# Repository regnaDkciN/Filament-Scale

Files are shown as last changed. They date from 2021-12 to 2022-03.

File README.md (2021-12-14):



# General

Like many other 3D printer users, I often find myself in a situation where I’m not sure if the spool I want to use has enough filament left to complete a print.  It is a guessing game in which I too often lose.  As a result, I created a scale that gives an accurate estimate of the amount of filament left on a given spool.  A quick internet search found several projects which were designed to do just that.  However, none of them were exactly what I was looking for.  Most of the projects were very well done.  Here are some of the scales that I especially liked:

- 	**Filament Health Monitor** at https://replicantfx.com/filament-health-monitor/ .  This scale gives humidity, temperature, and automatic detection of the color of the filament that is loaded..
- 	**Build a 3D Printer Filament Scale** in Nuts and Volts Magazine 2019/Issue-4.  For Nuts and Volts subscribers it can be found at https://nutsvolts.texterity.com/nutsvolts/201904/MobilePagedReplica.action?pm=2&folio=44#pg44 This scale is very well done and very well documented.  Some notable features are a database for many common filament types, latest settings are preserved through power cycles, and a nice display that uses a rotary encoder for selection.
- 	**Filament Holder and Scales** at https://www.youmagine.com/designs/filament-holder-and-scales .  This scale has fairly simple functionality, but I liked the 3D printed spool holder it presented, and I used it in my project.
- 	**3D Printer Filament Measuring with Arduino** at https://www.electroschematics.com/3d-printer-filament-measuring-arduino/ .  This scale is nice, but simple.

# Features

The scale presented here has the following features that I deemed useful:

- 	Accurate measurement of weight up to 5 kg with units selection of grams (g), kilograms (kg), ounces (oz), or pounds (lb).
- 	Accurate measure of filament length based on spool weight and filament density.  Length units are selectable as millimeters (mm), centimeters (cm), meters (m), inches (in), feet (ft), or yards (yd).
- 	Extensive user interface using a color 1.8” TFT display and rotary encoder.
- 	Menu driven option settings.
- 	Displays environmental data of temperature and humidity with selectable Fahrenheit/Celsius selection.
- 	Database of up to 15 spools with associated ID string, empty spool weight, filament color, filament type, filament density, and filament diameter.
- 	Database of default filament densities with 12 built-in default densities, and 3 user definable densities.
- 	WiFi compatible, with built-in web page.
- 	Non-volatile storage of all user settings which are preserved through power cycles.

#

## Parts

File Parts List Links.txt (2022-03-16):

Part                                      #   Link
------------------------------------------------------------------------------------------------------------------------------------------------------------------------------------------------------------------
Adafruit HUZZAH32 – ESP32 Feather         1   https://learn.adafruit.com/adafruit-huzzah32-esp32-feather
Adafruit 1.8” TFT Display                 1   https://www.adafruit.com/product/358
HX711 ADC Converter with 5KG Load Cell    1   https://www.amazon.com/gp/product/B078W2VCP2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
DHT22 Temperature and Humidity Sensor     1   https://www.adafruit.com/product/385
Rotary Encoder with Switch Module         1   https://www.microcenter.com/product/618904/inland-ks0013-keystudio-rotary-encoder-module
SPST N.O. Pushbutton Switch (16mm)        1   https://www.amazon.com/gp/product/B07DM2YMT4/ref=ppx_yo_dt_b_asin_title_o01_s00?ie=UTF8&psc=1
DPDT Rocker Switch (3/4”)                 1   https://www.radioshack.com/products/dpdt-red-rocker-switch
Resistor, 10K 1/8 Watt                    1
5V Power Supply with Micro USB Connector  1   https://www.microcenter.com/product/510437/micro-connectors-micro-usb-5v-25a-power-adapter-with-on-off-switch-for-raspberry-pi
2-Pin Connector, 0.1”                     1   https://www.allelectronics.com/item/con-242/2-pin-connector-w/header-.10/1.html
3-Pin Connector, 0.1”                     1   https://www.allelectronics.com/item/con-243/3-pin-connector-w/header-0.1/1.html
4-Pin Connector, 0.1”                     3   https://www.allelectronics.com/item/con-244/4-pin-connector-w/header-0.10/1.html
10-Pin Connector, 0.1”                    1   https://www.allelectronics.com/item/con-2410/10-pin-connector-w/header-0.1-spacing/1.html
Hookup Wire
608ZZ Bearing                             4   https://www.amazon.com/gp/product/B00NX1WBA0/ref=ppx_yo_dt_b_asin_title_o03_s00?ie=UTF8&psc=1
Assorted M2 and M3 Screws
M3 Threaded Brass Inserts                15   https://www.amazon.com/gp/product/B07NBTCHP1/ref=ppx_yo_dt_b_asin_title_o04_s00?ie=UTF8&psc=1
M3 x 6mm Screw                           15
M3 x 12mm Screw                           6
½” Self-Adhesive Foam Pads                4   https://www.acehardware.com/departments/home-and-decor/cabinet-and-furniture-hardware/protective-furniture-pads/5089586
½” Rubber Grommet                         1   https://www.harborfreight.com/180-piece-harness-grommet-set-67582.html
4” Cable Ties (100 pack)                  5   https://www.harborfreight.com/4-in-white-cable-ties-100-pk-60257.html
3/32” Heat Shrink Tubing                      https://www.harborfreight.com/127-piece-heat-shrink-tubing-set-67524.html
Knob for Rotary Encoder

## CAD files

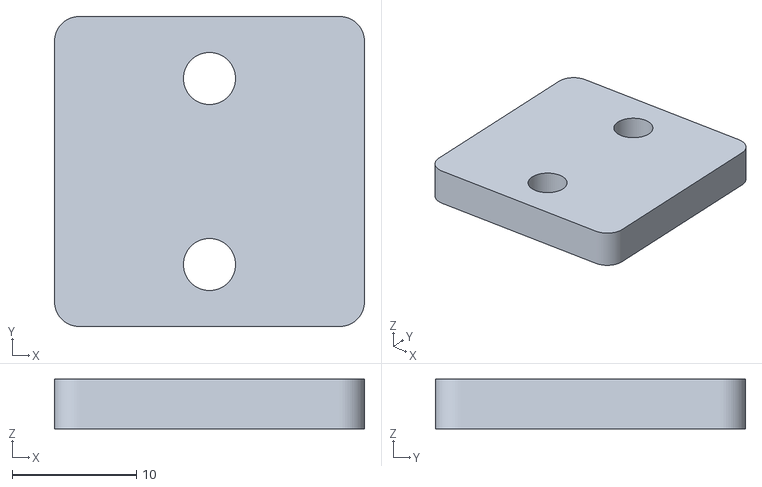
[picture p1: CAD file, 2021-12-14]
STL Files/Filament Scale - Load Cell Mount.stl
25.0 x 25.0 x 4.00

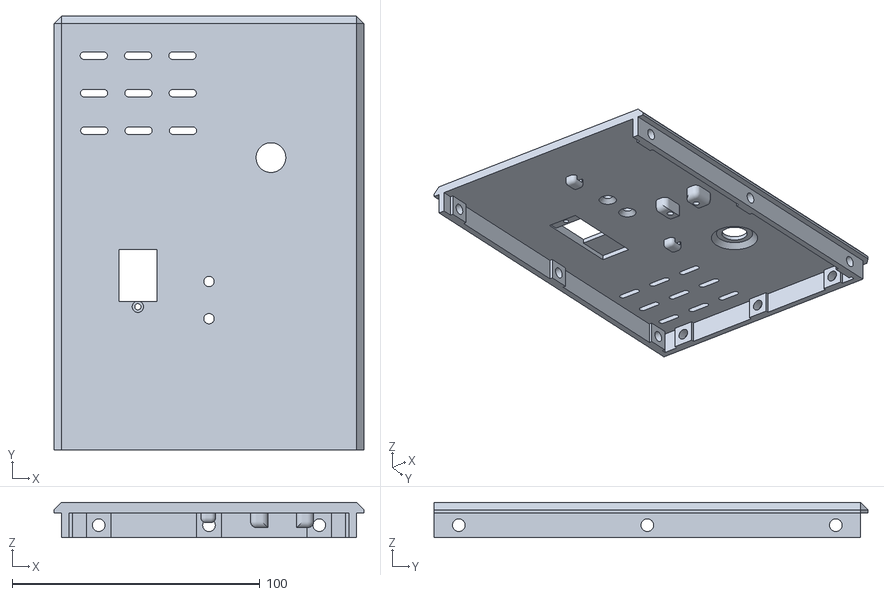
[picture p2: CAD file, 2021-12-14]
STL Files/Filament Scale - Top.stl
125.0 x 175.1 x 14.2

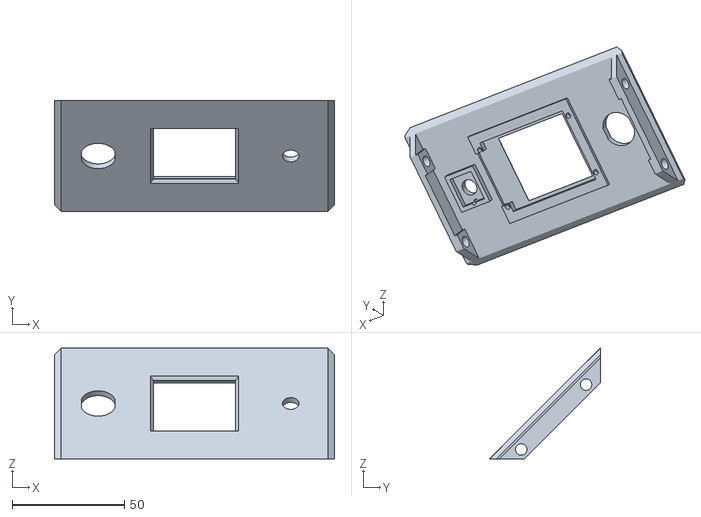
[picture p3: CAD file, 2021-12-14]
STL Files/Filament Scale - Sloped Front.stl
125.0 x 49.5 x 49.5

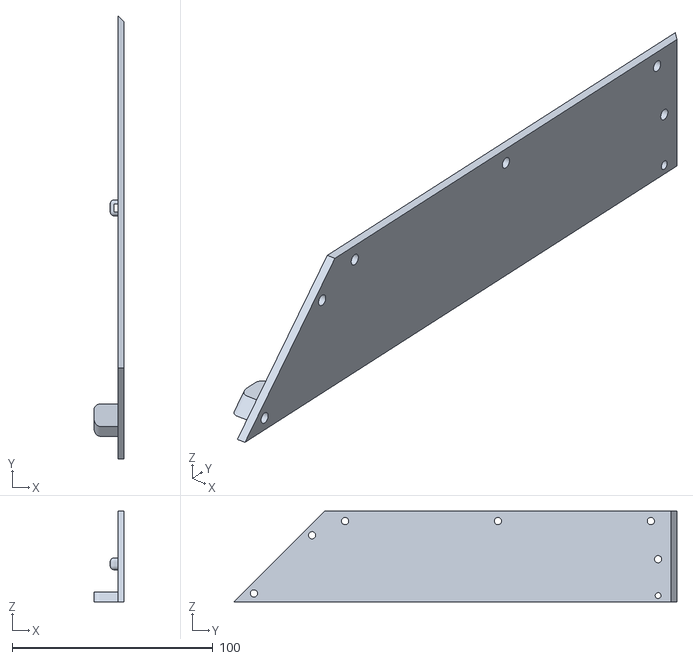
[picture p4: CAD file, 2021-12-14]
STL Files/Filament Scale - Right Side.stl
15.0 x 220.4 x 45.3

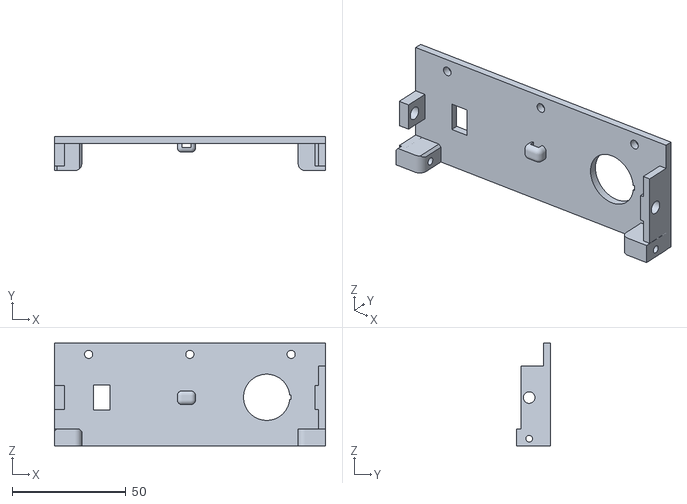
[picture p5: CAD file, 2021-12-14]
STL Files/Filament Scale - Back.stl
119.1 x 15.0 x 45.3

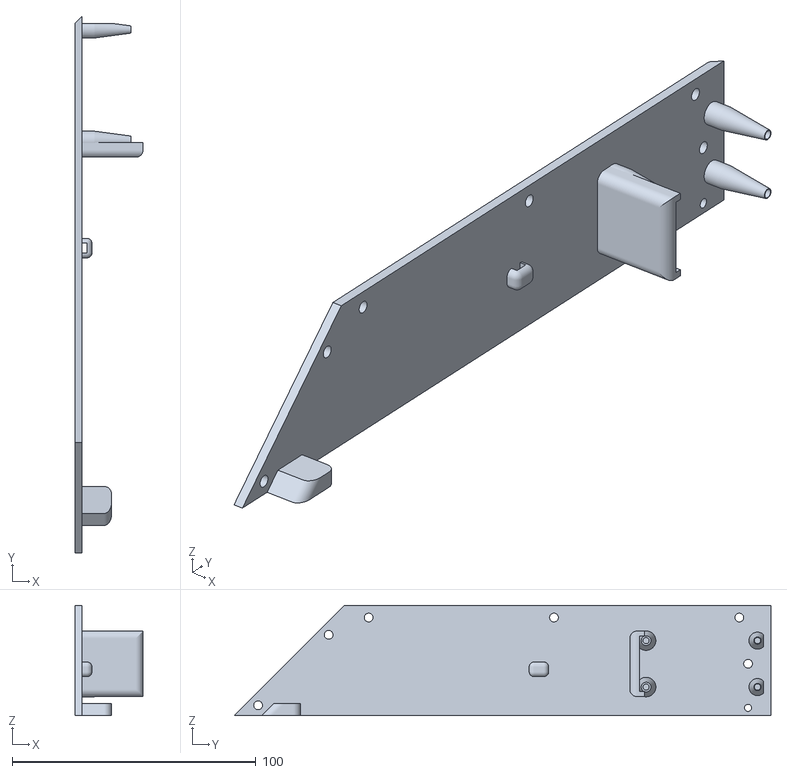
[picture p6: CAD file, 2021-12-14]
STL Files/Filament Scale - Left Side.stl
28.0 x 220.4 x 45.3

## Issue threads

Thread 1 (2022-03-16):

BOM links do not work

mmally, 2022-03-16:
First congratulations to this fine scale! I would like to build one of my own, but and try to source the components.
Which is not that easy in Europe.

In the "Filament Scale Instructions.pdf" the Hardware Parts links do not work. Other links in the pdf work fine.
I tested it with two different viewers.
This would save me a lot of work.

regnaDkciN, 2022-03-16:
I'm glad you liked it.  Thanks for catching the absence of the links.  I don't know why they don't work.  I've attached a text version of the parts list with links to this email.  I'll post a copy of it to the github site.
Good luck with your build.

    On Wednesday, March 16, 2022, 10:00:20 AM EDT, mmally ***@***.***> wrote:

First congratulations to this fine scale! I would like to build one of my own, but and try to source the components.
Which is not that easy in Europe.

In the "Filament Scale Instructions.pdf" the Hardware Parts links do not work. Other links in the pdf work fine.
I tested it with two different viewers.
This would save me a lot of work.

—
Reply to this email directly, view it on GitHub, or unsubscribe.
Triage notifications on the go with GitHub Mobile for iOS or Android.
You are receiving this because you are subscribed to this thread.Message ID: ***@***.***>

Part                                      #   Link
------------------------------------------------------------------------------------------------------------------------------------------------------------------------------------------------------------------
Adafruit HUZZAH32 – ESP32 Feather         1   https://learn.adafruit.com/adafruit-huzzah32-esp32-feather
Adafruit 1.8” TFT Display                 1   https://www.adafruit.com/product/358
HX711 ADC Converter with 5KG Load Cell    1   https://www.amazon.com/gp/product/B078W2VCP2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
DHT22 Temperature and Humidity Sensor     1   https://www.adafruit.com/product/385
Rotary Encoder with Switch Module         1   https://www.microcenter.com/product/618904/inland-ks0013-keystudio-rotary-encoder-module
SPST N.O. Pushbutton Switch (16mm)        1   https://www.amazon.com/gp/product/B07DM2YMT4/ref=ppx_yo_dt_b_asin_title_o01_s00?ie=UTF8&psc=1
DPDT Rocker Switch (3/4”)                 1   https://www.radioshack.com/products/dpdt-red-rocker-switch
Resistor, 10K 1/8 Watt                    1
5V Power Supply with Micro USB Connector  1   https://www.microcenter.com/product/510437/micro-connectors-micro-usb-5v-25a-power-adapter-with-on-off-switch-for-raspberry-pi
2-Pin Connector, 0.1”                     1   https://www.allelectronics.com/item/con-242/2-pin-connector-w/header-.10/1.html
3-Pin Connector, 0.1”                     1   https://www.allelectronics.com/item/con-243/3-pin-connector-w/header-0.1/1.html
4-Pin Connector, 0.1”                     3   https://www.allelectronics.com/item/con-244/4-pin-connector-w/header-0.10/1.html
10-Pin Connector, 0.1”                    1   https://www.allelectronics.com/item/con-2410/10-pin-connector-w/header-0.1-spacing/1.html
Hookup Wire
608ZZ Bearing                             4   https://www.amazon.com/gp/product/B00NX1WBA0/ref=ppx_yo_dt_b_asin_title_o03_s00?ie=UTF8&psc=1
Assorted M2 and M3 Screws
M3 Threaded Brass Inserts                15   https://www.amazon.com/gp/product/B07NBTCHP1/ref=ppx_yo_dt_b_asin_title_o04_s00?ie=UTF8&psc=1
M3 x 6mm Screw                           15
M3 x 12mm Screw                           6
½” Self-Adhesive Foam Pads                4   https://www.acehardware.com/departments/home-and-decor/cabinet-and-furniture-hardware/protective-furniture-pads/5089586
½” Rubber Grommet                         1   https://www.harborfreight.com/180-piece-harness-grommet-set-67582.html
4” Cable Ties (100 pack)                  5   https://www.harborfreight.com/4-in-white-cable-ties-100-pk-60257.html
3/32” Heat Shrink Tubing                      https://www.harborfreight.com/127-piece-heat-shrink-tubing-set-67524.html
Knob for Rotary Encoder

mmally, 2022-03-17:
Thank you very much for the BOM.

What is the reason for limiting the spool database to 15?

I have seen that the TFT Display also has a SD Card slot. I am thinking about using this for storing all the filament spool data (currently I have about 50 of them). Adafruit uses this just for  storing pictures, so I am not sure if it is also accessible via SPI and regular libraries.
I also have an idea to add an RFID reader to automatically identify a spool and update the database automatically.

regnaDkciN, 2022-03-17:
The main reason that the database is limited to 15 entries is that the menu system can only handle a maximum of 15 items per page.  I suppose you might be able to add multiple pages for the database, or modify the menu code to support more than 15 items.  However, I was a professional programmer for 40 years and I found the ArduinoMenu library extremely difficult to work with.  It uses deeply nested macros and contains only a few comments.  I spent more time trying to get it to do what I needed than I did on the entire rest of the project.
The storage for the database is not a problem.  I think there is enough memory left over in the system to support 50 spools.  However, it would be easy to use the SD card slot for that purpose if you wanted to.  My initial tests with the SD card slot on the TFT display showed that it was pretty easy to use.  You may have noticed on the wiring diagram that the SD card select is wired to the Huzzah even though the software does not use it.  So all you would need to do would be to add the appropriate library and interface to it.
The RFID sounds like a great idea.  I don't think it would be very difficult to add.  Of course there would be some code changes in both the menu subsystem and the main system that would be needed.

    On Thursday, March 17, 2022, 06:17:55 AM EDT, mmally ***@***.***> wrote:

Thank you very much for the BOM.

What is the reason for limiting the spool database to 15?

I have seen that the TFT Display also has a SD Card slot. I am thinking about using this for storing all the filament spool data (currently I have about 50 of them). Adafruit uses this just for storing pictures, so I am not sure if it is also accessible via SPI and regular libraries.
I also have an idea to add an RFID reader to automatically identify a spool and update the database automatically.

—
Reply to this email directly, view it on GitHub, or unsubscribe.
Triage notifications on the go with GitHub Mobile for iOS or Android.
You are receiving this because you modified the open/close state.Message ID: ***@***.***>

mmally, 2022-03-17:
Thank you for the valuable input regarding the menu library.
I will first build the scale, add RFID and then think about how to expand the database.

Cheers from Austria

regnaDkciN, 2022-03-17:
I'm glad I could help.  I hope your build goes well.

    On Thursday, March 17, 2022, 05:44:37 PM EDT, mmally ***@***.***> wrote:

Thank you for the valuable input regarding the menu library.
I will first build the scale, add RFID and then think about how to expand the database.

Cheers from Austria

—
Reply to this email directly, view it on GitHub, or unsubscribe.
Triage notifications on the go with GitHub Mobile for iOS or Android.
You are receiving this because you modified the open/close state.Message ID: ***@***.***>

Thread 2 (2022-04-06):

Wont compile - "passing 'const LoadCell' as 'this' argument discards qualifiers [-fpermissive]"

bencoton, 2022-04-06:
Can you please help with the code? I am having multiple failures however the failure in the title seems to be the greatest failure.

I am using Arduino IDE 1.8.19

In file included from C:\Users\bcoto\OneDrive\Desktop\Filament Scale\Filament-Scale-main\SourceFiles\JmcFilamentScale\LoadCell.cpp:13:0:
C:\Users\bcoto\OneDrive\Desktop\Filament Scale\Filament-Scale-main\SourceFiles\JmcFilamentScale\LoadCell.h: In member function 'int32_t LoadCell::ReadARawValue() const':
LoadCell.h:336:50: error: passing 'const LoadCell' as 'this' argument discards qualifiers [-fpermissive]
     int32_t ReadARawValue()  const { return read(); }
                                                  ^
In file included from C:\Users\bcoto\OneDrive\Desktop\Filament Scale\Filament-Scale-main\SourceFiles\JmcFilamentScale\LoadCell.h:17:0,
                 from C:\Users\bcoto\OneDrive\Desktop\Filament Scale\Filament-Scale-main\SourceFiles\JmcFilamentScale\LoadCell.cpp:13:
C:\Users\bcoto\OneDrive\Documents\Arduino\libraries\HX711/HX711.h:54:12: note:   in call to 'float HX711::read()'
   float    read();
            ^
In file included from C:\Users\bcoto\OneDrive\Desktop\Filament Scale\Filament-Scale-main\SourceFiles\JmcFilamentScale\LoadCell.cpp:13:0:
C:\Users\bcoto\OneDrive\Desktop\Filament Scale\Filament-Scale-main\SourceFiles\JmcFilamentScale\LoadCell.h: In member function 'double LoadCell::ReadARawValueD() const':
LoadCell.h:337:70: error: passing 'const LoadCell' as 'this' argument discards qualifiers [-fpermissive]
     double  ReadARawValueD() const { return static_cast<double>(read()); }
                                                                      ^
In file included from C:\Users\bcoto\OneDrive\Desktop\Filament Scale\Filament-Scale-main\SourceFiles\JmcFilamentScale\LoadCell.h:17:0,
                 from C:\Users\bcoto\OneDrive\Desktop\Filament Scale\Filament-Scale-main\SourceFiles\JmcFilamentScale\LoadCell.cpp:13:
C:\Users\bcoto\OneDrive\Documents\Arduino\libraries\HX711/HX711.h:54:12: note:   in call to 'float HX711::read()'
   float    read();
            ^
C:\Users\bcoto\OneDrive\Desktop\Filament Scale\Filament-Scale-main\SourceFiles\JmcFilamentScale\LoadCell.cpp: In constructor 'LoadCell::LoadCell(int, int, uint8_t)':
LoadCell.cpp:49:26: error: no matching function for call to 'LoadCell::begin(int&, int&, uint8_t&)'
     begin(dout, sck, gain);
                          ^
In file included from C:\Users\bcoto\OneDrive\Desktop\Filament Scale\Filament-Scale-main\SourceFiles\JmcFilamentScale\LoadCell.h:17:0,
                 from C:\Users\bcoto\OneDrive\Desktop\Filament Scale\Filament-Scale-main\SourceFiles\JmcFilamentScale\LoadCell.cpp:13:
C:\Users\bcoto\OneDrive\Documents\Arduino\libraries\HX711/HX711.h:38:12: note: candidate: void HX711::begin(uint8_t, uint8_t)
   void     begin(uint8_t dataPin, uint8_t clockPin);
            ^
C:\Users\bcoto\OneDrive\Documents\Arduino\libraries\HX711/HX711.h:38:12: note:   candidate expects 2 arguments, 3 provided
C:\Users\bcoto\OneDrive\Desktop\Filament Scale\Filament-Scale-main\SourceFiles\JmcFilamentScale\LoadCell.cpp: In member function 'bool LoadCell::IsPresent() const':
LoadCell.cpp:142:35: error: passing 'const LoadCell' as 'this' argument discards qualifiers [-fpermissive]
     if (!wait_ready_retry(10U, 10U) || (ReadARawValue() == 0L))
                                   ^
In file included from C:\Users\bcoto\OneDrive\Desktop\Filament Scale\Filament-Scale-main\SourceFiles\JmcFilamentScale\LoadCell.h:17:0,
                 from C:\Users\bcoto\OneDrive\Desktop\Filament Scale\Filament-Scale-main\SourceFiles\JmcFilamentScale\LoadCell.cpp:13:
C:\Users\bcoto\OneDrive\Documents\Arduino\libraries\HX711/HX711.h:49:12: note:   in call to 'bool HX711::wait_ready_retry(uint8_t, uint32_t)'
   bool     wait_ready_retry(uint8_t retries = 3, uint32_t ms = 0);
            ^
At global scope:
cc1plus.exe: warning: unrecognized command line option '-Wno-frame-address'
In file included from C:\Users\bcoto\OneDrive\Desktop\Filament Scale\Filament-Scale-main\SourceFiles\JmcFilamentScale\JmcFilamentScale.h:16:0,
                 from C:\Users\bcoto\OneDrive\Desktop\Filament Scale\Filament-Scale-main\SourceFiles\JmcFilamentScale\HslColor.h:16,
                 from C:\Users\bcoto\OneDrive\Desktop\Filament Scale\Filament-Scale-main\SourceFiles\JmcFilamentScale\HslColor.cpp:14:
C:\Users\bcoto\OneDrive\Desktop\Filament Scale\Filament-Scale-main\SourceFiles\JmcFilamentScale\LoadCell.h: In member function 'int32_t LoadCell::ReadARawValue() const':
LoadCell.h:336:50: error: passing 'const LoadCell' as 'this' argument discards qualifiers [-fpermissive]
     int32_t ReadARawValue()  const { return read(); }
                                                  ^
In file included from C:\Users\bcoto\OneDrive\Desktop\Filament Scale\Filament-Scale-main\SourceFiles\JmcFilamentScale\LoadCell.h:17:0,
                 from C:\Users\bcoto\OneDrive\Desktop\Filament Scale\Filament-Scale-main\SourceFiles\JmcFilamentScale\JmcFilamentScale.h:16,
                 from C:\Users\bcoto\OneDrive\Desktop\Filament Scale\Filament-Scale-main\SourceFiles\JmcFilamentScale\HslColor.h:16,
                 from C:\Users\bcoto\OneDrive\Desktop\Filament Scale\Filament-Scale-main\SourceFiles\JmcFilamentScale\HslColor.cpp:14:
C:\Users\bcoto\OneDrive\Documents\Arduino\libraries\HX711/HX711.h:54:12: note:   in call to 'float HX711::read()'
   float    read();
            ^
In file included from C:\Users\bcoto\OneDrive\Desktop\Filament Scale\Filament-Scale-main\SourceFiles\JmcFilamentScale\JmcFilamentScale.h:16:0,
                 from C:\Users\bcoto\OneDrive\Desktop\Filament Scale\Filament-Scale-main\SourceFiles\JmcFilamentScale\HslColor.h:16,
                 from C:\Users\bcoto\OneDrive\Desktop\Filament Scale\Filament-Scale-main\SourceFiles\JmcFilamentScale\HslColor.cpp:14:
C:\Users\bcoto\OneDrive\Desktop\Filament Scale\Filament-Scale-main\SourceFiles\JmcFilamentScale\LoadCell.h: In member function 'double LoadCell::ReadARawValueD() const':
LoadCell.h:337:70: error: passing 'const LoadCell' as 'this' argument discards qualifiers [-fpermissive]
     double  ReadARawValueD() const { return static_cast<double>(read()); }
                                                                      ^
In file included from C:\Users\bcoto\OneDrive\Desktop\Filament Scale\Filament-Scale-main\SourceFiles\JmcFilamentScale\LoadCell.h:17:0,
                 from C:\Users\bcoto\OneDrive\Desktop\Filament Scale\Filament-Scale-main\SourceFiles\JmcFilamentScale\JmcFilamentScale.h:16,
                 from C:\Users\bcoto\OneDrive\Desktop\Filament Scale\Filament-Scale-main\SourceFiles\JmcFilamentScale\HslColor.h:16,
                 from C:\Users\bcoto\OneDrive\Desktop\Filament Scale\Filament-Scale-main\SourceFiles\JmcFilamentScale\HslColor.cpp:14:
C:\Users\bcoto\OneDrive\Documents\Arduino\libraries\HX711/HX711.h:54:12: note:   in call to 'float HX711::read()'
   float    read();
            ^
In file included from C:\Users\bcoto\OneDrive\Desktop\Filament Scale\Filament-Scale-main\SourceFiles\JmcFilamentScale\JmcFilamentScale.h:18:0,
                 from C:\Users\bcoto\OneDrive\Desktop\Filament Scale\Filament-Scale-main\SourceFiles\JmcFilamentScale\HslColor.h:16,
                 from C:\Users\bcoto\OneDrive\Desktop\Filament Scale\Filament-Scale-main\SourceFiles\JmcFilamentScale\HslColor.cpp:14:
C:\Users\bcoto\OneDrive\Desktop\Filament Scale\Filament-Scale-main\SourceFiles\JmcFilamentScale\SpoolManager.h: In member function 'bool SpoolManager<N>::Save() const':
SpoolManager.h:406:9: error: 'Preferences' was not declared in this scope
         Preferences prefs;
         ^
SpoolManager.h:407:9: error: 'prefs' was not declared in this scope
         prefs.begin(m_pName);
         ^
C:\Users\bcoto\OneDrive\Desktop\Filament Scale\Filament-Scale-main\SourceFiles\JmcFilamentScale\SpoolManager.h: In member function 'bool SpoolManager<N>::Restore()':
SpoolManager.h:460:9: error: 'Preferences' was not declared in this scope
         Preferences prefs;
         ^
SpoolManager.h:461:9: error: 'prefs' was not declared in this scope
         prefs.begin(m_pName);
         ^
C:\Users\bcoto\OneDrive\Desktop\Filament Scale\Filament-Scale-main\SourceFiles\JmcFilamentScale\SpoolManager.h: In member function 'bool SpoolManager<N>::Reset()':
SpoolManager.h:498:9: error: 'Preferences' was not declared in this scope
         Preferences prefs;
         ^
SpoolManager.h:499:9: error: 'prefs' was not declared in this scope
         prefs.begin(m_pName);
         ^
In file included from C:\Users\bcoto\OneDrive\Desktop\Filament Scale\Filament-Scale-main\SourceFiles\JmcFilamentScale\JmcFilamentScale.h:16:0,
                 from C:\Users\bcoto\OneDrive\Desktop\Filament Scale\Filament-Scale-main\SourceFiles\JmcFilamentScale\MainScreen.cpp:12:
C:\Users\bcoto\OneDrive\Desktop\Filament Scale\Filament-Scale-main\SourceFiles\JmcFilamentScale\LoadCell.h: In member function 'int32_t LoadCell::ReadARawValue() const':
LoadCell.h:336:50: error: passing 'const LoadCell' as 'this' argument discards qualifiers [-fpermissive]
     int32_t ReadARawValue()  const { return read(); }
                                                  ^
In file included from C:\Users\bcoto\OneDrive\Desktop\Filament Scale\Filament-Scale-main\SourceFiles\JmcFilamentScale\LoadCell.h:17:0,
                 from C:\Users\bcoto\OneDrive\Desktop\Filament Scale\Filament-Scale-main\SourceFiles\JmcFilamentScale\JmcFilamentScale.h:16,
                 from C:\Users\bcoto\OneDrive\Desktop\Filament Scale\Filament-Scale-main\SourceFiles\JmcFilamentScale\MainScreen.cpp:12:
C:\Users\bcoto\OneDrive\Documents\Arduino\libraries\HX711/HX711.h:54:12: note:   in call to 'float HX711::read()'
   float    read();
            ^
In file included from C:\Users\bcoto\OneDrive\Desktop\Filament Scale\Filament-Scale-main\SourceFiles\JmcFilamentScale\JmcFilamentScale.h:16:0,
                 from C:\Users\bcoto\OneDrive\Desktop\Filament Scale\Filament-Scale-main\SourceFiles\JmcFilamentScale\MainScreen.cpp:12:
C:\Users\bcoto\OneDrive\Desktop\Filament Scale\Filament-Scale-main\SourceFiles\JmcFilamentScale\LoadCell.h: In member function 'double LoadCell::ReadARawValueD() const':
LoadCell.h:337:70: error: passing 'const LoadCell' as 'this' argument discards qualifiers [-fpermissive]
     double  ReadARawValueD() const { return static_cast<double>(read()); }
                                                                      ^
In file included from C:\Users\bcoto\OneDrive\Desktop\Filament Scale\Filament-Scale-main\SourceFiles\JmcFilamentScale\LoadCell.h:17:0,
                 from C:\Users\bcoto\OneDrive\Desktop\Filament Scale\Filament-Scale-main\SourceFiles\JmcFilamentScale\JmcFilamentScale.h:16,
                 from C:\Users\bcoto\OneDrive\Desktop\Filament Scale\Filament-Scale-main\SourceFiles\JmcFilamentScale\MainScreen.cpp:12:
C:\Users\bcoto\OneDrive\Documents\Arduino\libraries\HX711/HX711.h:54:12: note:   in call to 'float HX711::read()'
   float    read();
            ^
In file included from C:\Users\bcoto\OneDrive\Desktop\Filament Scale\Filament-Scale-main\SourceFiles\JmcFilamentScale\JmcFilamentScale.h:18:0,
                 from C:\Users\bcoto\OneDrive\Desktop\Filament Scale\Filament-Scale-main\SourceFiles\JmcFilamentScale\MainScreen.cpp:12:
C:\Users\bcoto\OneDrive\Desktop\Filament Scale\Filament-Scale-main\SourceFiles\JmcFilamentScale\SpoolManager.h: In member function 'bool SpoolManager<N>::Save() const':
SpoolManager.h:406:9: error: 'Preferences' was not declared in this scope
         Preferences prefs;
         ^
SpoolManager.h:407:9: error: 'prefs' was not declared in this scope
         prefs.begin(m_pName);
         ^
C:\Users\bcoto\OneDrive\Desktop\Filament Scale\Filament-Scale-main\SourceFiles\JmcFilamentScale\SpoolManager.h: In member function 'bool SpoolManager<N>::Restore()':
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

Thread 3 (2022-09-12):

Some errors while trying to build

xyzroe, 2022-09-12:
Hi.
Great work, thanks.
I'm trying to build firmware using your instruction (new clean Arduino IDE v1.8.19, all libraries from table 4 were installed, menu and hx711 files were replaced) but I got a few errors that I tried to fix.
So far I have not had success, but maybe you can help me.

1. _DHT.h: No such file or directory_  - I tried different versions of 'DHT sensor library for ESPx', but all of them used DHTesp.h not DHT.h as in your project. I change to DHTesp.h, according to https://github.com/beegee-tokyo/DHTesp/blob/master/examples/DHT_ESP32/DHT_ESP32.ino#L1
2. _WiFiManager.h: No such file or directory_  - I installed https://github.com/tzapu/WiFiManager that is not mentioned in table 4, but I found this link at https://github.com/regnaDkciN/Filament-Scale/blob/03aa03c5be18ce4ef94d06465c40cf69e46beec1/SourceFiles/JmcFilamentScale/Network.h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
3. _JmcFilamentScale\EnvSensor.cpp:13: EnvSensor.h:35:1: error: expected class-name before '{' token_  - I changed 'class EnvSensor : private DHT' to 'class EnvSensor : private DHTesp'
4. _EnvSensor.h:41:15: error: class 'EnvSensor' does not have any field named 'DHT'_ - I changed 'DHT(dataPin, type)' to 'DHTesp(dataPin, type)'
5. _EnvSensor.h:41:81: error: no matching function for call to 'DHTesp::DHTesp(uint8_t&, uint8_t&)'_ - And here I have no more ideas.

Maybe I need to install some other library for DHT?

What am I doing wrong?

UPD: I installed [DHT sensor library](https://github.com/adafruit/DHT-sensor-library) and it turned out to be a successful build. I will test.

xyzroe, 2022-09-12:
I made a [fork](https://github.com/xyzroe/Filament-Scale) that supports PlatformIO right out of the box.

The main advantage is that you do not need to download the libraries by hand - everything will be downloaded by itself at the time of the first build of the project.
There is also no need to replace the library files, since the two libraries that need to be changed are included in the project with all the necessary changes.
I tried to make a minimum of changes in the project files in order to leave the opportunity to develop using Arduino IDE.

If you find an opportunity to study my solution and it seems interesting and acceptable to you, I will gladly make a PR.

regnaDkciN, 2022-09-12:
Hi xyzroe,
Does this mean you overcame the errors you reported earlier?  I've only recently started using PlatformIO and am glad that you made a fork for it.I will check your fork when I get a chance.  May take a few days.
Joe

    On Monday, September 12, 2022 at 02:08:13 PM EDT, xyzroe ***@***.***> wrote:

I made a fork that supports PlatformIO right out of the box.

The main advantage is that you do not need to download the libraries by hand - everything will be downloaded by itself at the time of the first build of the project.
There is also no need to replace the library files, since the two libraries that need to be changed are included in the project with all the necessary changes.
I tried to make a minimum of changes in the project files in order to leave the opportunity to develop using Arduino IDE.

If you find an opportunity to study my solution and it seems interesting and acceptable to you, I will gladly make a PR.

—
Reply to this email directly, view it on GitHub, or unsubscribe.
You are receiving this because you are subscribed to this thread.Message ID: ***@***.***>

xyzroe, 2022-09-12:
Yes, I overcame those errors. I edited the first message as soon as I found the solution.

Regarding the fork: I made the possibility of automatic build directly on GitHub, it seems to me convenient.
Also made a little order in the organization of the files, so that the repository would look easier.

So far, I don’t have a weight sensor or a screen, so I can’t do full-fledged tests. But in general, build goes without remarks, wifi connected, the DHT readings are received. So I think everything should be fine.

regnaDkciN, 2022-09-12:
Looks like I unintentionally referenced the wrong DHT library in the PDF file.  The correct one is the Adafruit "DHT sensor library"  which can be found and installed in the Arduino library manager.  It doesn't explicitly state that it works with the ESP32, but it works OK for me.  However, if your changes using DHTesp work, then by all means use them.  Regarding WiFiManager, the link in the PDF file is correct and you should have been able to find it.  However, again, if the file you found works for you then go ahead and use it.
Disclaimer: I actually started work on the scale in 2019, so some of the things (parts and / or libraries) I used may have been superseded by now, or better ones may be available.  Feel free to change whatever anything you need to make it work for you.

    On Monday, September 12, 2022 at 06:14:03 PM EDT, xyzroe ***@***.***> wrote:

Yes, I overcame those errors. I edited the first message as soon as I found the solution.

Regarding the fork: I made the possibility of automatic build directly on GitHub, it seems to me convenient.
Also made a little order in the organization of the files, so that the repository would look easier.

So far, I don’t have a weight sensor or a screen, so I can’t do full-fledged tests. But in general, build goes without remarks, wifi connected, the DHT readings are received. So I think everything should be fine.

—
Reply to this email directly, view it on GitHub, or unsubscribe.
You are receiving this because you commented.Message ID: ***@***.***>

Closed 2022-09-14.

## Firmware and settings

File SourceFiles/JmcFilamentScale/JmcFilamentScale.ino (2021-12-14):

/////////////////////////////////////////////////////////////////////////////////
// JmcFilamentScale.ino
//
// Implements a filament scale with the following features:
//   - Menu driven settings.
//   - Selectable weight units display (g, kg, oz, lb).
//   - Weigh items up to 5kg (11 lb).
//   - Addjustable display brightness.
//   - Built-in temperature display.
//   - Built-in humidity display.
//   - Selectable temperature units (degrees C or F).
//   - Storage for data for up to 15 filament spools.
//   - Adjustable spool parameters include:
//      - Spool name (up to 8 characters).
//      - Filament type (15 selectable filament types).
//      - Empty spool weight.
//      - Filament diameter.
//   - Adjustable filament density for eoach of the 15 filament types.
//   - Calculation and display of remaining length of filament per spool.
//   - Selectable filament length units (mm, cm, m, in, ft, yd).
//   - Ability to save settings to NVS for restoration on powerup.
//   - Web interface with ability to monitor all data and modify all options
//     remotely.
//
//  This implementation relies heavily on the ArdiunoMenu library:
//      https://github.com/neu-rah/ArduinoMenu
//
// This code is menat to run on an ESP32 microprocessor with the following or
// similar peripherals:
//      - Adafruit HUZZAH32 - ESP32 Feather Board.
//        https://www.adafruit.com/product/3405
//      - Adafruit 1.8" 128x160  TFT display.
//        https://www.adafruit.com/product/358
//      - 5kg Load Cell and HX711.
//        https://www.amazon.com/gp/product/B075317R45/ref=ppx_yo_dt_b_asin_title_o02_s00?ie=UTF8&psc=1
//      - DHT22 Digital Temperature and Himidity Sensor.
//        https://www.amazon.com/gp/product/B07T63JRT8/ref=ppx_yo_dt_b_asin_title_o00_s00?ie=UTF8&psc=1
//      - Rotaty Encoder with Pushbutton Module.
//        https://www.amazon.com/gp/product/B081YCR3JC/ref=ppx_yo_dt_b_asin_title_o04_s00?ie=UTF8&psc=1
//
// This project was inspired by an article in "Nuts and Volts" magazine
// 2019 Issue-4.  The article is entitled "Build a 3D Printer Filament Scale" by
// Edward Andrews.  I used a few small code fragments from the article, and the
// filament density table from the article.  Additional inspiration was gathered
// from "Filament Health Monitor" at https://replicantfx.com/filament-health-monitor/
//
// History:
// - jmcorbett 04-JAN-2021 Original creation.
//
// Copyright (c) 2021, Joseph M. Corbett
/////////////////////////////////////////////////////////////////////////////////

#include "JmcFilamentScale.h"   // For global variables and extern definitioins.
#include <menu.h>               // For ArduinoMenu.
#include <menuIO/adafruitGfxOut.h>// For Adafruit graphics library.
#include <menuIO/chainStream.h> // For menu input/output streams.
#include <menuIO/serialOut.h>   // For menu serial output.
#include <menuIO/serialIn.h>    // For menu serial input.
#include <plugin/userMenu.h>    // For OBJ menu macro.
#include "ESP32EncoderStream.h" // For encoder w/pushbutton.
#include "MainScreen.h"         // For MainScreen related stuff.
#include "WebData.h"            // For web page handling code.
#include "ScaleMenu.h"          // For menu  related stuff.
#include "AuxPb.h"              // For AuxPb class.


/////////////////////////////////////////////////////////////////////////////////
// ST7735 1.8TFT 128x160 Pin assignments and related variables.
/////////////////////////////////////////////////////////////////////////////////
static const int TFT_CS   = 14;     // TFT display CS pin.
static const int TFT_DC   = 32;     // TFT display DC pin.
static const int TFT_RST  = 15;     // TFT display RST pin.
static const int TFT_LITE = A0;     // TFT display backlight pin.

// Construct our TFT  object.
// Adafruit_ST7735 gTft(TFT_CS, TFT_DC, TFT_RST);
Display gTft(TFT_CS, TFT_DC, TFT_RST, TFT_LITE);

// TFT related globals and constants.
uint32_t           gBacklightPercent = 100;
static const char *gTftNvsName       = "Dispaly";


/////////////////////////////////////////////////////////////////////////////////
// Rotary encoder pins.
/////////////////////////////////////////////////////////////////////////////////
static const int ENC_PIN_A      = A3;   // Encoder A pin.
static const int ENC_PIN_B      = A4;   // Encoder B pin.
static const int ENC_BUTTON_PIN = 13;   // Encoder pushbutton pin.
static const int ENC_SENSITIVITY = 4;   // Encoder sensitivity.

// Construct the pushbutton encoder stream object.  Note that some encoders will
// require the sensitivity to be set to a different value.
ESP32EncoderStream gEncStream(ENC_PIN_A, ENC_PIN_B, ENC_BUTTON_PIN, ENC_SENSITIVITY);


/////////////////////////////////////////////////////////////////////////////////
// Auxiliary pushbutton pins.
/////////////////////////////////////////////////////////////////////////////////
static const int AUX_BUTTON_PIN = A1;   // Auxiliary pushbutton pin.

// Construct the auxiliary pushbutton object.
AuxPb gAuxPb(AUX_BUTTON_PIN);


/////////////////////////////////////////////////////////////////////////////////
// Define the LoadCell sensor related I/O pins and global data and constants.
/////////////////////////////////////////////////////////////////////////////////
static const int LOADCELL_DOUT_PIN  = A2;   // LoadCell DOUT signal pin.
static const int LOADCELL_SCK_PIN   = A5;   // LoadCell CLOCK pin.

// Construct and init the LoadCell object.
LoadCell gLoadCell(LOADCELL_DOUT_PIN, LOADCELL_SCK_PIN, 128U);

// Load cell related globals and constants.
       WeightUnits gScaleUnits        = eWuGrams;
       uint32_t    gScaleAveragingSamples =
                   (AVG_SAMPLES_DEFAULT_MS + WEIGHT_UPDATE_PERIOD_MS / 2) /
                   WEIGHT_UPDATE_PERIOD_MS;
       uint8_t     gScaleGain         = 128;
static const char *gLoadCellNvsName   = "Load Cell";
       float       gCurrentWeight     = 0.0f;
       float       gCurrentLength     = 0.0f;


/////////////////////////////////////////////////////////////////////////////////
// Define the environmental sensor (temperature and humidity) pins and global
// data and constants.
/////////////////////////////////////////////////////////////////////////////////
static const uint8_t ENV_DAT_PIN    = 27;   // Sensor data pin.
static const uint8_t ENV_TYPE       = DHT22;// Sensor type.

// Construct and init the EnvSensor object.
EnvSensor gEnvSensor(ENV_DAT_PIN, ENV_TYPE);

// Environmental sensor related globals and constants.
TempScale gTemperatureUnits     = eTempScaleF;
static const char *gEnvSensorNvsName   = "Env Sensor";
       float       gCurrentTemperature = 0.0f;
       float       gCurrentHumidity    = 0.0f;


/////////////////////////////////////////////////////////////////////////////////
// Filament class related data and constants.
/////////////////////////////////////////////////////////////////////////////////
Filament gFilament;

// Filament related global data and constants.
       float  gWorkingFilamentDensity = 0.01;
       char   gWorkingFilamentType[Filament::TYPE_STRING_MAX_SIZE] = { 0 };
static const char *gFilamentNvsName  = "Filament";


/////////////////////////////////////////////////////////////////////////////////
// Spool Manager related data and constants.
/////////////////////////////////////////////////////////////////////////////////
SpoolManager<NUMBER_SPOOLS> gSpoolMgr;

// Set up spool related global data.  Used for dynamic menu implementation.
       SpoolData gWorkingSpoolData; // Spool data currently being worked om.
static const char *gSpoolMgrNvsName  = "Spool Mgr";


/////////////////////////////////////////////////////////////////////////////////
// LengthManager related data and constants.
/////////////////////////////////////////////////////////////////////////////////
LengthManager gLengthMgr;

// Length manager related globals and constants.
static const       LengthUnits DEFAULT_LENGTH_UNITS = luMm;
                   LengthUnits  gLengthUnits        = DEFAULT_LENGTH_UNITS;
static float       gLengthFactor                    = 0.0;
static const char *gLengthMgrNvsName                = "Length Mgr";


/////////////////////////////////////////////////////////////////////////////////
// Network related data and constants.
/////////////////////////////////////////////////////////////////////////////////
static const int   SERVER_PORT = 80;
       Network     gNetwork(SERVER_PORT);

// NVS name.
static const char *gNetworkNvsName    = "Network";

// Access the scale via this name (i.e. http://JmcScale.local).
const char *gNetworkServerName = "JmcScale";
const char * &rNetworkServerName = gNetworkServerName;


/////////////////////////////////////////////////////////////////////////////////
// Main Screen related data and constants.
/////////////////////////////////////////////////////////////////////////////////
static const char *gMainScreenNvsName = "Main Screen";


/////////////////////////////////////////////////////////////////////////////////
// Weight related data.
/////////////////////////////////////////////////////////////////////////////////
static const  double MAX_CAL_WEIGHT = 5000.0;
static const  double MIN_CAL_WEIGHT = 0.0;
       double gCalibrateWeight      = MIN_CAL_WEIGHT;
       double gMinWeight            = MIN_CAL_WEIGHT;
       double gMaxWeight            = MAX_CAL_WEIGHT;
       double gBigWeightStep        = 10.0;
       double gSmallWeightStep      = .1;


/////////////////////////////////////////////////////////////////////////////////
// Miscellaneous globals.
/////////////////////////////////////////////////////////////////////////////////
       bool   gRunningMenu          = false;
       bool   gDataUpdated          = false;

/////////////////////////////////////////////////////////////////////////////////
// SetDecimalPlaces()
//
// Rounds a double value to a specified precision (number of digits to the right
// of the decimal point).
//
// Arguments:
//  value     - this is the value that will be rounded.
//  precision - this is the number of digits to the right of the decimal point
//              to keep.
//
// Returns:
//   Returns the rounded value.
/////////////////////////////////////////////////////////////////////////////////
double SetDecimalPlaces(double value, int precision)
{
    double factor = pow(10, precision);
    value *= factor;
    value = ceil(value);
    value /= factor;
    return value;
}


/////////////////////////////////////////////////////////////////////////////////
// GetMinScaleWeight()
//
// Returns the minimum allowable scale weight given the current weight units.
// Currently always returns 0.0.  May change in the future.
/////////////////////////////////////////////////////////////////////////////////
static double GetMinScaleWeight()
{
    double minWeight = 0.0;
    switch(gLoadCell.GetUnits())
    {
    case eWuGrams:     minWeight = 0.0; break;
    case eWuKiloGrams: minWeight = 0.0; break;
    case eWuOunces:    minWeight = 0.0; break;
    case eWuPounds:    minWeight = 0.0; break;
    default:           minWeight = 0.0; break;
    }
    return minWeight;
} // End GetMinScaleWeight().


/////////////////////////////////////////////////////////////////////////////////
// GetMaxScaleWeight()
//
// Returns the maximum allowable scale weight given the current weight units.
/////////////////////////////////////////////////////////////////////////////////
double GetMaxScaleWeight()
{
    double maxWeight = 10.0;
    switch(gLoadCell.GetUnits())
    {
    case eWuGrams:     maxWeight = 5000.0; break;
    case eWuKiloGrams: maxWeight = 5.0;    break;
    case eWuOunces:    maxWeight = 176.37; break;
    case eWuPounds:    maxWeight = 11.02;  break;
    default:           maxWeight = 5000.0; break;
    }
    return maxWeight;
} // End GetMaxScaleWeight().


/////////////////////////////////////////////////////////////////////////////////
// GetWeightBigStep()
//
// Returns the size of a large step for when editing weight values based on
// the currently selected weight units.
/////////////////////////////////////////////////////////////////////////////////
static double GetWeightBigStep()
{
    double step = 10.0;
    switch(gLoadCell.GetUnits())
    {
    case eWuGrams:     step = 10.0; break;
    case eWuKiloGrams: step = 0.01; break;
    case eWuOunces:    step = 1.0;  break;
    case eWuPounds:    step = 0.1;  break;
    default:           step = 10.0; break;
    }
    return step;
} // End GetWeightBigStep().


/////////////////////////////////////////////////////////////////////////////////
// GetWeightSmallStep()
//
// Returns the size of a small step for when editing weight values based on
// the currently selected weight units.
/////////////////////////////////////////////////////////////////////////////////
static double GetWeightSmallStep()
{
    double step = 0.1;
    switch(gLoadCell.GetUnits())
    {
    case eWuGrams:     step = 0.1;    break;
    case eWuKiloGrams: step = 0.0001; break;
    case eWuOunces:    step = 0.01;   break;
    case eWuPounds:    step = 0.001;  break;
    default:           step = 0.1;    break;
    }
    return step;
} // End GetWeightSmallStep().


/////////////////////////////////////////////////////////////////////////////////
// GetWeightDecimalPlaces()
//
// Returns the number of digits to display to the right of the decimal point
// based on the currently selected weight units.
/////////////////////////////////////////////////////////////////////////////////
int GetWeightDecimalPlaces()
{
        int decimalPlaces = 1;
        switch(gLoadCell.GetUnits())
        {
        case eWuGrams:     decimalPlaces = 1; break;
        case eWuKiloGrams: decimalPlaces = 4; break;
        case eWuOunces:    decimalPlaces = 2; break;
        case eWuPounds:    decimalPlaces = 3; break;
        default:           decimalPlaces = 1; break;
        }
        return decimalPlaces;
} // End GetWeightDecimalPlaces().


/////////////////////////////////////////////////////////////////////////////////
// SaveSpoolOffset()
//
// If a spool is selected, then save its offset value as the current load cell
// offset.  Otherwise, save a value of 0.0.
/////////////////////////////////////////////////////////////////////////////////
void SaveSpoolOffset()
{
    double currentSpoolOffset = 0.0;

    Spool *pSelectedSpool = gSpoolMgr.GetSelectedSpool();
    if (pSelectedSpool != NULL)
    {
        currentSpoolOffset = pSelectedSpool->GetSpoolWeight();
    }
    gLoadCell.SetOffset(currentSpoolOffset);
} // End SaveSpoolOffset().


/////////////////////////////////////////////////////////////////////////////////
// UpdateLengthFactor()
//
// If a spool is selected, then update our length factor.  Otherwise, save a
// value of 0.0.
/////////////////////////////////////////////////////////////////////////////////
void UpdateLengthFactor()
{
    // Initially reset the length factor.
    gLengthFactor = 0.0;

    // Only update the length factor if a spool is selected.
    Spool *pSelectedSpool = gSpoolMgr.GetSelectedSpool();
    if ((gLoadCell.IsCalibrated()) && (pSelectedSpool != NULL))
    {
        gLengthFactor = gLengthMgr.CalculateLengthFactor(
                        pSelectedSpool->GetDiameter(),
                        gLoadCell.GetBaseUnitsFactor(gScaleUnits),
                        pSelectedSpool->GetDensity());
    }
} // End UpdateLengthFactor().


/////////////////////////////////////////////////////////////////////////////////
// SetLoadCellUnits()
//
// Updates our load cell (weight) units, then scales all spool table weights
// based on the new units.
/////////////////////////////////////////////////////////////////////////////////
void SetLoadCellUnits(WeightUnits units)
{
    // Update our weight units and edit limits.
    gLoadCell.SetUnits(units);
    gMinWeight = GetMinScaleWeight();
    gMaxWeight = GetMaxScaleWeight();
    gBigWeightStep   = GetWeightBigStep();
    gSmallWeightStep = GetWeightSmallStep();

    // Determine our multiplier based on the new weight units.
    double multiplier = gLoadCell.GetConversionFactor();

    // Scale the spool weights for the entire spool table based on the new units.
    for (uint16_t i = 0; i < NUMBER_SPOOLS; i++)
    {
        Spool *pSpool = gSpoolMgr.GetSpool(i);
        float weight = pSpool->GetSpoolWeight() * multiplier;
        pSpool->SetSpoolWeight(weight);
    }
} // End SetLoadCellUnits().
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
void loop()
{
    // Number of milliseconds to delay at the end of each loop() execution.
    const uint32_t LOOP_DELAY = 2;

    // Always update the scale weight and environmental data.
    UpdateCurrentWeight();
    UpdateCurrentEnv();

    // Always handle the network.
    gNetwork.Process();

    // If web had the lock and timed out, then clear the lock.
    WebData::HandleWebTimeout();

    // Handle the Aux Pushbutton.  Must be done before net/menu polling.
    HandleAuxPb();

    // Are we running the menu now?
    if (gRunningMenu)
    {
        // Yes, run the menu subsystem.
        gNavRoot.poll();
    }
    else
    {
        // No, display the main screen.
        HandleMainScreen();
    }

    // Delay to allow background to run.
    delay(LOOP_DELAY);
} // End loop().

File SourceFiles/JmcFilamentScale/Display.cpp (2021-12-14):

/////////////////////////////////////////////////////////////////////////////////
// Display.cpp
//
// Contains miscellaneous methods used by the scale display.
//
// History:
// - jmcorbett 26-DEC-2020 Original creation.
//
// Copyright (c) 2021, Joseph M. Corbett
/////////////////////////////////////////////////////////////////////////////////

#include <Preferences.h>        // For NVS save/restore.
#include "Display.h"            // Our own class definition.
#include "JmcFilamentScale.h"   // For BOX_RADIUS.
#include "ScaleIcon.h"          // For ScaleIcon .


// Some constants used by the class.
const size_t Display::MAX_NVS_NAME_LEN     = 15U;
const char  *Display::pPrefSavedStateLabel = "Saved State";
const double Display::BACKLIGHT_FREQUENCY  = 5000.0d;


/////////////////////////////////////////////////////////////////////////////////
// Constructor
//
// Initialize our instance data and setup for use of the backlight and
// initializes the TFT hardware and library with a blank screen.
//
// Arguments:
//    - csPin        - Display's CS pin.
//    - dcPin        - Display's DC pin.
//    - rstPin       - Display's RST pin.
//    - backlightPin - Display's backlight pin.
//    - displayType  - Display type identified by colored tab on the display's
//                     plastic overlay.  (INITR_GREENTAB, INITR_REDTAB, or
//                     INITR_BLACKTAB).
//    - rotation     - Display's rotation orientation  (0, 1, 2, or 3).
/////////////////////////////////////////////////////////////////////////////////
Display::Display(int csPin, int dcPin, int rstPin, int backlightPin,
                 uint8_t displayType, uint8_t rotation) :
        Adafruit_ST7735(csPin, dcPin, rstPin), m_pName(NULL),
        m_BacklightPin(backlightPin), m_BacklightPercent(0)
{
    // Configure the lite functionality.
    ledcSetup(BACKLIGHT_CHANNEL, BACKLIGHT_FREQUENCY, BACKLIGHT_RESOLUTION);

    // Attach the analog channel to the GPIO pin to be controlled.
    ledcAttachPin(m_BacklightPin, BACKLIGHT_CHANNEL);

    // Set the gBacklight brightness.
    ledcWrite(BACKLIGHT_CHANNEL, BACKLIGHT_MIN_BRIGHTNESS);

    // The 1.8" TFT display from Adafruit seems to have a startup problem in
    // which many times on initial power-up it doesn't get initialized
    // properly and just shows a blank white screen.  The following code
    // resets the display before initializing it in the hope of working around
    // this problem.  Since this is a constructor, the delay() function will not
    // work. We use delayMicroseconds() in its place, which should work in
    // constructors.  The following section of code does the same thing as
    // the reset that is done in Adafruit_SPITFT::initSPI(), but uses
    // delayMicroseconds() instead of delay().
    // Note that argument to delayMicroseconds() must be less than 16K, so the
    // delays used here all use 1000 uS or 1ms as a basis, and loop the
    // appropriate amount of times to affect the needed long delays.
    pinMode(rstPin, OUTPUT);
    digitalWrite(rstPin, HIGH);
    // delay(100);  // Delay 100 ms.
    int i = 0;
    for (i = 0; i < 100; i++)
    {
        delayMicroseconds(1000);
    }
    digitalWrite(rstPin, LOW);
    // delay(100);  // Delay 100 ms.
    for (i = 0; i < 100; i++)
    {
        delayMicroseconds(1000);
    }
    digitalWrite(rstPin, HIGH);
    // delay(200);  // Delay 200 ms.
    for (i = 0; i < 200; i++)
    {
        delayMicroseconds(1000);
    }

    // Setup the display hardware and firmware library.
    initR(displayType);
    setRotation(rotation);
    fillScreen(ST7735_BLACK);
} // End constructor.


/////////////////////////////////////////////////////////////////////////////////
// Init()
//
// This method initializes the filament class.
//
// Arguments:
//    - pName   - A string of no more than 15 characters to be used as a
//                name for this instance.  This is mainly used to identify
//                the instance to be used for NVS save and restore.
//
// Returns:
//    Returns a bool indicating whether or not the initialization was
//    successful.  A 'true' value indicates success, while a 'false' value
//    indicates failure.
//
/////////////////////////////////////////////////////////////////////////////////
bool Display::Init(const char *pName)
{
    // Assume we're gonna fail.
    bool status = false;

    // Make sure the name is valid.  If not then we fail.
    if ((pName != NULL) && (*pName != '\0') && (strlen(pName) <= MAX_NVS_NAME_LEN))
    {
        // Name was OK.  Save it and remember that we succeeded.
        m_pName            = pName;
        status             = true;
    }
    return status;
} // End Init().


/////////////////////////////////////////////////////////////////////////////////
// SetBacklightPercent()
//
// Sets the backlight level to a percentage of its maximum brightness.
//
// Arguments:
//    - percent - This is the percentage of maximum brightness which the
//                backlight will be set to.  Valid values are 0 through
//                100 inclusive.
//
// Returns:
//    Returns 'true' if successful.  Returns 'false' if an invalid 'level' value
//    was passed.
/////////////////////////////////////////////////////////////////////////////////
bool Display::SetBacklightPercent(uint32_t percent)
{
    bool status = false;

    if (percent <= 100)
    {
        m_BacklightPercent = percent;
        uint32_t backlightValue =
          (percent * (BACKLIGHT_MAX_BRIGHTNESS - BACKLIGHT_MIN_BRIGHTNESS) / 100) +
           BACKLIGHT_MIN_BRIGHTNESS;
        ledcWrite(BACKLIGHT_CHANNEL, backlightValue);
        status = true;
    }
    return status;
} // End SetBacklightPercent().
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

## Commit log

2021-12-14 Add files via upload
    Original upload.
    [Filament Scale - Back.stl, Filament Scale - Left Side.stl, Filament Scale - Load Cell Mount.stl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]
2022-08-30 Changed Spool.cpp - SetColor() to return void. Fixed SkipItemDown() and SkipItemUpDown() in ScaleMenu.cpp to return the correct status.
    [ScaleMenu.cpp]

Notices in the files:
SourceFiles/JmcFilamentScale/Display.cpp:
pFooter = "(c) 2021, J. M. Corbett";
